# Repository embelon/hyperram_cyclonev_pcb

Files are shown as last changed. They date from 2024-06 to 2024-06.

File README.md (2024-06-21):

# Expansion PCB for Cyclone V SoC Development Kit

Using HSMC connector.

On board:
- 8MB HyperRAM memory: S27KL0641DABHI020
- 16MB HyperFlash : S26KL128SDABHI020
- 4MB QSPI FlashNOR: W25Q32JVSSIQ

I/O
- HDMI output
- 2 x PMOD (3V3): PMOD1 (J6), PMOD2 (7)
- 1 x PMOD (3V3 or 5V): PMOD3 (J5)
- 8bit LA header (shared signals with PMOD3/J5)
- 7 debug signals

### Images
top
bottom

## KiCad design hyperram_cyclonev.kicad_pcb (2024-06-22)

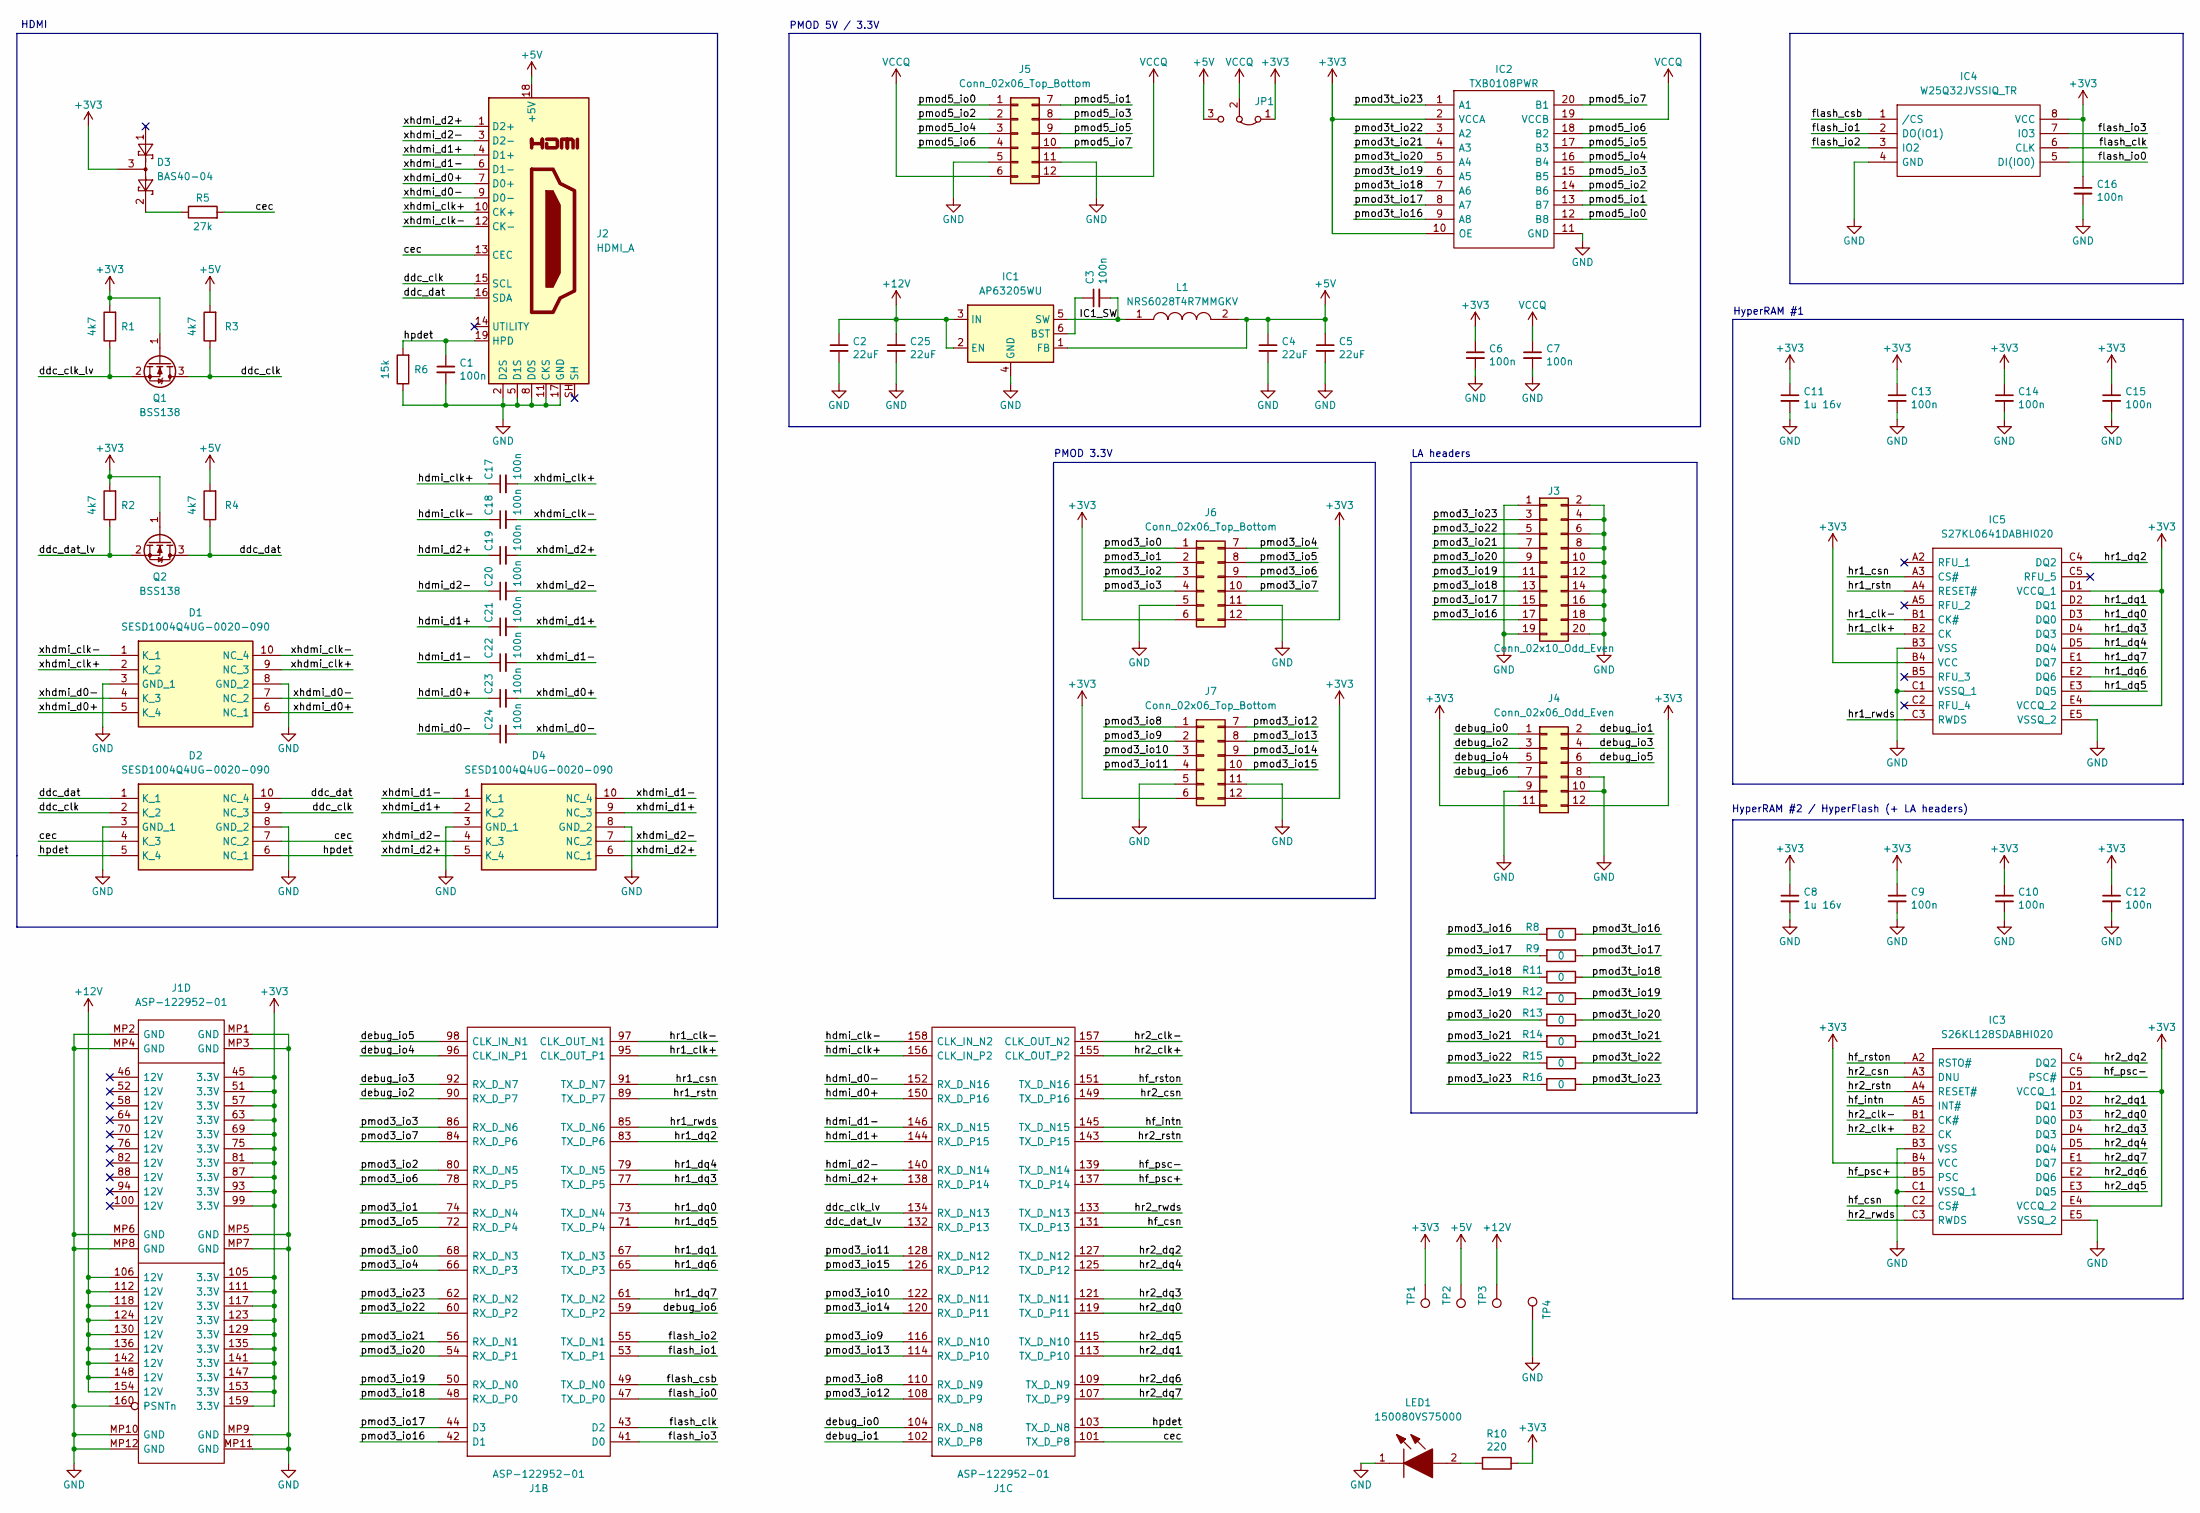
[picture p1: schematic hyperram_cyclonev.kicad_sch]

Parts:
C1, C9, C10, C12, C13, C14, C15, C16: 100n; C_0603_1608Metric_Pad1.08x0.95mm_HandSolder; Part CGA3E2X7R1H223K080AA
C2, C4, C5, C25: 22uF; C_0805_2012Metric_Pad1.18x1.45mm_HandSolder; Part CL21A226MAYNNNE
C3, C6, C7: 100n; C_0603_1608Metric_Pad1.08x0.95mm_HandSolder; Part 06033C104KAT2A
C8, C11: 1u 16v; C_0805_2012Metric_Pad1.18x1.45mm_HandSolder; Part CL10A105KO8NNNC
C17, C18, C19, C20, C21, C22, C23, C24: 100n; C_0402_1005Metric_Pad0.74x0.62mm_HandSolder; Part 06033C104KAT2A
D1, D2, D4: SESD1004Q4UG-0020-090; SESD1004Q4UG0020090; Mouser Part Number 650-SESD1004Q4UG0020
D3: BAS40-04; SOT-23
IC1: AP63205WU; TSOT-23-6
IC2: TXB0108PWR; SOP65P640X120-20N; Mouser Part Number 595-TXB0108PWR
IC3: S26KL128SDABHI020; BGA24C100P5X5_600X800X100; Mouser Part Number 727-S26KL128SDABHI02
IC4: W25Q32JVSSIQ_TR; SOIC127P790X216-8N; Mouser Part Number 454-W25Q32JVSSIQTR
IC5: S27KL0641DABHI020; BGA24C100P5X5_600X800X100; Manufacturer_Part_Number S27KL0641DABHI020; Mouser Part Number 727-S27KL0641DABHI02
J1: ASP-122952-01; ASP12295201; Manufacturer_Part_Number ASP-122952-01; Mouser Part Number 200-ASP-122952-01
J2: HDMI_A; 685119134923
J3: Conn_02x10_Odd_Even; PinHeader_2x10_P2.54mm_Vertical
J4: Conn_02x06_Odd_Even; PinHeader_2x06_P2.54mm_Vertical
J5, J6, J7: Conn_02x06_Top_Bottom; 610112249221_PMOD_Bottom
JP1: Jumper_3_Bridged12; PinHeader_1x03_P2.54mm_Vertical
L1: NRS6028T4R7MMGKV; NRS6028T4R7MMGK; Mouser Part Number 963-NRS6028T4R7MMGKV
LED1: 150080VS75000; LEDC2012X80N; Mouser Part Number 710-150080VS75000
Q1, Q2: BSS138; SOT-23
R1, R2, R3, R4: 4k7; R_0603_1608Metric_Pad0.98x0.95mm_HandSolder
R5: 27k; R_0603_1608Metric_Pad0.98x0.95mm_HandSolder
R6: 15k; R_0603_1608Metric_Pad0.98x0.95mm_HandSolder
R8, R9, R11, R12, R13, R14, R15, R16: 0; R_0402_1005Metric_Pad0.72x0.64mm_HandSolder
R10: 220; R_0603_1608Metric_Pad0.98x0.95mm_HandSolder; Part ‎RC0603JR-07100RL‎
TP1: 3V3; TestPoint_Pad_D1.0mm
TP2: 5V; TestPoint_Pad_D1.0mm
TP3: 12V; TestPoint_Pad_D1.0mm
TP4: GND; TestPoint_Pad_D1.0mm

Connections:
+3V3: C6.1, C8.1, C9.1, C10.1, C11.1, C12.1, C13.1, C14.1, C15.1, C16.1, D3.3, IC2.2 (VCCA), IC2.10 (OE), IC3.B4 (VCC), IC3.D1 (VCCQ_1), IC3.E4 (VCCQ_2), IC4.8 (VCC), IC5.B4 (VCC), IC5.D1 (VCCQ_1), IC5.E4 (VCCQ_2), J1.45 (3.3V), J1.51 (3.3V), J1.57 (3.3V), J1.63 (3.3V), J1.69 (3.3V), J1.75 (3.3V), J1.81 (3.3V), J1.87 (3.3V), J1.93 (3.3V), J1.99 (3.3V), J1.105 (3.3V), J1.111 (3.3V), J1.117 (3.3V), J1.123 (3.3V), J1.129 (3.3V), J1.135 (3.3V), J1.141 (3.3V), J1.147 (3.3V), J1.153 (3.3V), J1.159 (3.3V), J4.11, J4.12, J6.6, J6.12, J7.6, J7.12, JP1.1 (A), Q1.1 (G), Q2.1 (G), R1.2, R2.2, R10.1, TP1.1
+5V: C4.1, C5.1, IC1.1 (FB), J2.18 (+5V), JP1.3 (B), L1.2, R3.2, R4.2, TP2.1
+12V: C2.1, C25.1, IC1.2 (EN), IC1.3 (IN), J1.106 (12V), J1.112 (12V), J1.118 (12V), J1.124 (12V), J1.130 (12V), J1.136 (12V), J1.142 (12V), J1.148 (12V), J1.154 (12V), TP3.1
/IC1_SW: C3.2, IC1.5 (SW), L1.1
/cec: D2.4 (K_3), D2.7 (NC_2), J1.101 (TX_D_P8), J2.13 (CEC), R5.2
/ddc_clk: D2.2 (K_2), D2.9 (NC_3), J2.15 (SCL), Q1.3 (D), R3.1
/ddc_clk_lv: J1.134 (RX_D_N13), Q1.2 (S), R1.1
/ddc_dat: D2.1 (K_1), D2.10 (NC_4), J2.16 (SDA), Q2.3 (D), R4.1
/ddc_dat_lv: J1.132 (RX_D_P13), Q2.2 (S), R2.1
/debug_io0: J1.104 (RX_D_N8), J4.1
/debug_io1: J1.102 (RX_D_P8), J4.2
/debug_io2: J1.90 (RX_D_P7), J4.3
/debug_io3: J1.92 (RX_D_N7), J4.4
/debug_io4: J1.96 (CLK_IN_P1), J4.5
/debug_io5: J1.98 (CLK_IN_N1), J4.6
/debug_io6: J1.59 (TX_D_P2), J4.7
/flash_clk: IC4.6 (CLK), J1.43 (D2)
/flash_csb: IC4.1 (/CS), J1.49 (TX_D_N0)
/flash_io0: IC4.5 (DI(IO0)), J1.47 (TX_D_P0)
/flash_io1: IC4.2 (DO(IO1)), J1.53 (TX_D_P1)
/flash_io2: IC4.3 (IO2), J1.55 (TX_D_N1)
/flash_io3: IC4.7 (IO3), J1.41 (D0)
/hdmi_clk+: C17.1, J1.156 (CLK_IN_P2)
/hdmi_clk-: C18.1, J1.158 (CLK_IN_N2)
/hdmi_d0+: C23.1, J1.150 (RX_D_P16)
/hdmi_d0-: C24.1, J1.152 (RX_D_N16)
/hdmi_d1+: C21.1, J1.144 (RX_D_P15)
/hdmi_d1-: C22.1, J1.146 (RX_D_N15)
/hdmi_d2+: C19.1, J1.138 (RX_D_P14)
/hdmi_d2-: C20.1, J1.140 (RX_D_N14)
/hf_csn: IC3.C2 (CS#), J1.131 (TX_D_P13)
/hf_intn: IC3.A5 (INT#), J1.145 (TX_D_N15)
/hf_psc+: IC3.B5 (PSC), J1.137 (TX_D_P14)
/hf_psc-: IC3.C5 (PSC#), J1.139 (TX_D_N14)
/hf_rston: IC3.A2 (RSTO#), J1.151 (TX_D_N16)
/hpdet: C1.1, D2.5 (K_4), D2.6 (NC_1), J1.103 (TX_D_N8), J2.19 (HPD), R6.2
/hr1_clk+: IC5.B2 (CK), J1.95 (CLK_OUT_P1)
/hr1_clk-: IC5.B1 (CK#), J1.97 (CLK_OUT_N1)
/hr1_csn: IC5.A3 (CS#), J1.91 (TX_D_N7)
/hr1_dq0: IC5.D3 (DQ0), J1.73 (TX_D_N4)
/hr1_dq1: IC5.D2 (DQ1), J1.67 (TX_D_N3)
/hr1_dq2: IC5.C4 (DQ2), J1.83 (TX_D_P6)
/hr1_dq3: IC5.D4 (DQ3), J1.77 (TX_D_P5)
/hr1_dq4: IC5.D5 (DQ4), J1.79 (TX_D_N5)
/hr1_dq5: IC5.E3 (DQ5), J1.71 (TX_D_P4)
/hr1_dq6: IC5.E2 (DQ6), J1.65 (TX_D_P3)
/hr1_dq7: IC5.E1 (DQ7), J1.61 (TX_D_N2)
/hr1_rstn: IC5.A4 (RESET#), J1.89 (TX_D_P7)
/hr1_rwds: IC5.C3 (RWDS), J1.85 (TX_D_N6)
/hr2_clk+: IC3.B2 (CK), J1.155 (CLK_OUT_P2)
/hr2_clk-: IC3.B1 (CK#), J1.157 (CLK_OUT_N2)
/hr2_csn: IC3.A3 (DNU), J1.149 (TX_D_P16)
/hr2_dq0: IC3.D3 (DQ0), J1.119 (TX_D_P11)
/hr2_dq1: IC3.D2 (DQ1), J1.113 (TX_D_P10)
/hr2_dq2: IC3.C4 (DQ2), J1.127 (TX_D_N12)
/hr2_dq3: IC3.D4 (DQ3), J1.121 (TX_D_N11)
/hr2_dq4: IC3.D5 (DQ4), J1.125 (TX_D_P12)
/hr2_dq5: IC3.E3 (DQ5), J1.115 (TX_D_N10)
/hr2_dq6: IC3.E2 (DQ6), J1.109 (TX_D_N9)
/hr2_dq7: IC3.E1 (DQ7), J1.107 (TX_D_P9)
/hr2_rstn: IC3.A4 (RESET#), J1.143 (TX_D_P15)
/hr2_rwds: IC3.C3 (RWDS), J1.133 (TX_D_N13)
/pmod3_io0: J1.68 (RX_D_N3), J6.1
/pmod3_io1: J1.74 (RX_D_N4), J6.2
/pmod3_io2: J1.80 (RX_D_N5), J6.3
/pmod3_io3: J1.86 (RX_D_N6), J6.4
/pmod3_io4: J1.66 (RX_D_P3), J6.7
/pmod3_io5: J1.72 (RX_D_P4), J6.8
/pmod3_io6: J1.78 (RX_D_P5), J6.9
/pmod3_io7: J1.84 (RX_D_P6), J6.10
/pmod3_io8: J1.110 (RX_D_N9), J7.1
/pmod3_io9: J1.116 (RX_D_N10), J7.2
/pmod3_io10: J1.122 (RX_D_N11), J7.3
/pmod3_io11: J1.128 (RX_D_N12), J7.4
/pmod3_io12: J1.108 (RX_D_P9), J7.7
/pmod3_io13: J1.114 (RX_D_P10), J7.8
/pmod3_io14: J1.120 (RX_D_P11), J7.9
/pmod3_io15: J1.126 (RX_D_P12), J7.10
/pmod3_io16: J1.42 (D1), J3.17, R8.2
/pmod3_io17: J1.44 (D3), J3.15, R9.2
/pmod3_io18: J1.48 (RX_D_P0), J3.13, R11.2
/pmod3_io19: J1.50 (RX_D_N0), J3.11, R12.2
/pmod3_io20: J1.54 (RX_D_P1), J3.9, R13.2
/pmod3_io21: J1.56 (RX_D_N1), J3.7, R14.2
/pmod3_io22: J1.60 (RX_D_P2), J3.5, R15.2
/pmod3_io23: J1.62 (RX_D_N2), J3.3, R16.2
/pmod3t_io16: IC2.9 (A8), R8.1
/pmod3t_io17: IC2.8 (A7), R9.1
/pmod3t_io18: IC2.7 (A6), R11.1
/pmod3t_io19: IC2.6 (A5), R12.1
/pmod3t_io20: IC2.5 (A4), R13.1
/pmod3t_io21: IC2.4 (A3), R14.1
/pmod3t_io22: IC2.3 (A2), R15.1
/pmod3t_io23: IC2.1 (A1), R16.1
/pmod5_io0: IC2.12 (B8), J5.1
/pmod5_io1: IC2.13 (B7), J5.7
/pmod5_io2: IC2.14 (B6), J5.2
/pmod5_io3: IC2.15 (B5), J5.8
/pmod5_io4: IC2.16 (B4), J5.3
/pmod5_io5: IC2.17 (B3), J5.9
/pmod5_io6: IC2.18 (B2), J5.4
/pmod5_io7: IC2.20 (B1), J5.10
/xhdmi_clk+: C17.2, D1.2 (K_2), D1.9 (NC_3), J2.10 (CK+)
/xhdmi_clk-: C18.2, D1.1 (K_1), D1.10 (NC_4), J2.12 (CK-)
/xhdmi_d0+: C23.2, D1.5 (K_4), D1.6 (NC_1), J2.7 (D0+)
/xhdmi_d0-: C24.2, D1.4 (K_3), D1.7 (NC_2), J2.9 (D0-)
/xhdmi_d1+: C21.2, D4.2 (K_2), D4.9 (NC_3), J2.4 (D1+)
/xhdmi_d1-: C22.2, D4.1 (K_1), D4.10 (NC_4), J2.6 (D1-)
/xhdmi_d2+: C19.2, D4.5 (K_4), D4.6 (NC_1), J2.1 (D2+)
/xhdmi_d2-: C20.2, D4.4 (K_3), D4.7 (NC_2), J2.3 (D2-)
GND: C1.2, C2.2, C4.2, C5.2, C6.2, C7.2, C8.2, C9.2, C10.2, C11.2, C12.2, C13.2, C14.2, C15.2, C16.2, C25.2, D1.3 (GND_1), D1.8 (GND_2), D2.3 (GND_1), D2.8 (GND_2), D4.3 (GND_1), D4.8 (GND_2), IC1.4 (GND), IC2.11 (GND), IC3.B3 (VSS), IC3.C1 (VSSQ_1), IC3.E5 (VSSQ_2), IC4.4 (GND), IC5.B3 (VSS), IC5.C1 (VSSQ_1), IC5.E5 (VSSQ_2), J1.160 (PSNTn), J1.MP1 (GND), J1.MP2 (GND), J1.MP3 (GND), J1.MP4 (GND), J1.MP5 (GND), J1.MP6 (GND), J1.MP7 (GND), J1.MP8 (GND), J1.MP9 (GND), J1.MP10 (GND), J1.MP11 (GND), J1.MP12 (GND), J2.2 (D2S), J2.5 (D1S), J2.8 (D0S), J2.11 (CKS), J2.17 (GND), J3.1, J3.2, J3.4, J3.6, J3.8, J3.10, J3.12, J3.14, J3.16, J3.18, J3.19, J3.20, J4.8, J4.9, J4.10, J5.5, J5.11, J6.5, J6.11, J7.5, J7.11, LED1.1, R6.1, TP4.1
unnamed: D3.2, R5.1
unnamed: C3.1, IC1.6 (BST)
unnamed: LED1.2, R10.2
VCCQ: C7.1, IC2.19 (VCCB), J5.6, J5.12, JP1.2 (C)

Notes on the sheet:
PMOD 3.3V
LA headers
HDMI
HyperRAM #2 / HyperFlash (+ LA headers)
HyperRAM #1
PMOD 5V / 3.3V

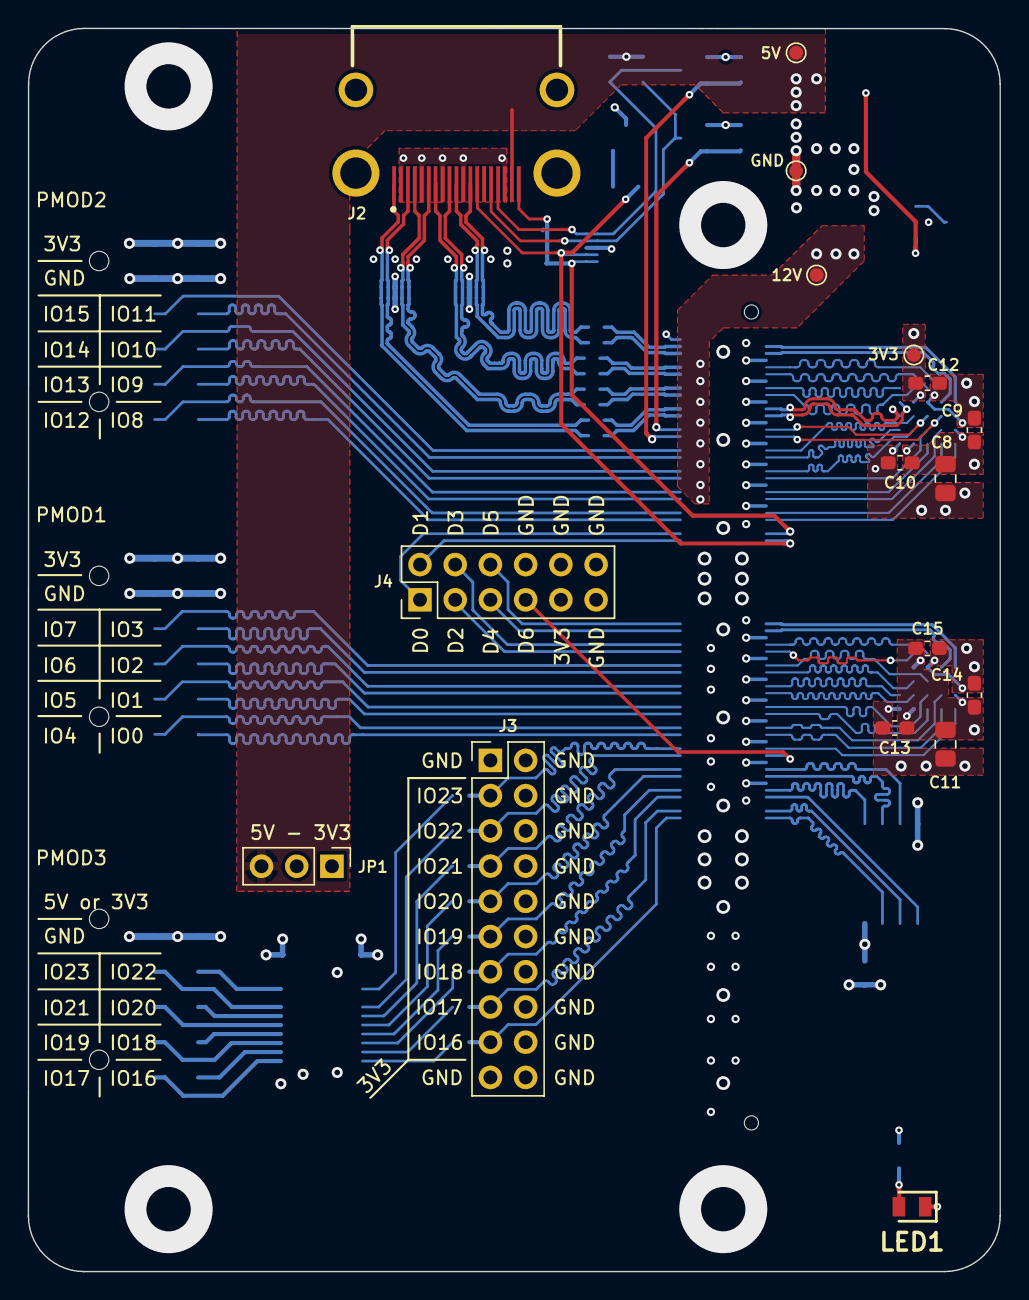
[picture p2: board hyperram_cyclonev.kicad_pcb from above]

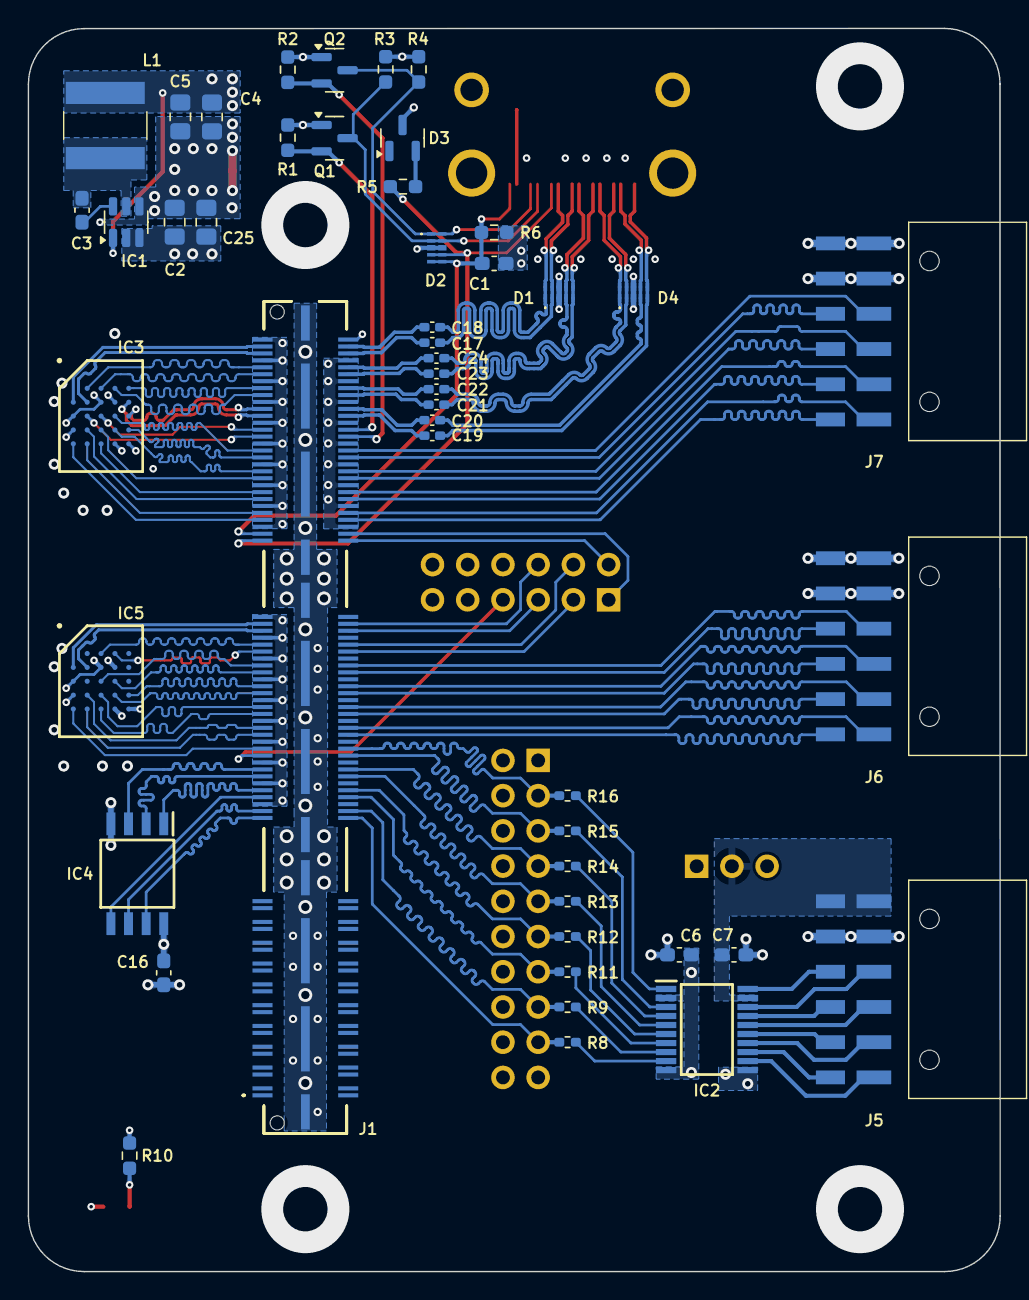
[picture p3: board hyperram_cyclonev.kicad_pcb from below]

Board: 4 copper layers, 70.1 x 89.6 mm, 65 parts (48 on the bottom side), 115 nets.

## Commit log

2022-09-15 Added PCB library
2022-10-16 Added DC/DC converter to get 5V for PMOD and HDMI from 12V. Changed two TXB0104 to one TXB0108 for PMOD 5V.
    [hyperram_cyclonev.kicad_sch]
2022-10-24 Updated schematics, made connections between PMODs, HyperBUS devices, Debug Header, QSPI NOR Flash, HDMI and HSMC.
    [hyperram_cyclonev.kicad_sch]
2023-08-11 Migrated to KiCad 7.
2023-08-11 Added 100nF capacitors in series for HDMI signals to get TMDS working with LVDS3 outputs on FPGA.
    [hyperram_cyclonev.kicad_sch]
2023-08-15 Fixed 2 issues with unconnected signals.
    [hyperram_cyclonev.kicad_sch]
2023-08-15 Updated symbols and footprints libraries.
2024-05-12 Fixed Schematics DRC warnings
    [hyperram_cyclonev.kicad_sch]
2024-05-13 Decreased number of ERC complaints. Assigned missing packages.
    [hyperram_cyclonev.kicad_sch]
2024-05-13 Loaded components into PCB.
    [hyperram_cyclonev.kicad_pcb, hyperram_cyclonev.kicad_sch]
2024-05-14 Fixed PCB footprint for PMOD
2024-05-14 Updated PCB footprint for HSMC
2024-05-14 Simplified schematic, removing unnecessary elements
    [hyperram_cyclonev.kicad_sch]
2024-05-14 Created edge.cuts. Updated PCB from schematic.
    [hyperram_cyclonev.kicad_pcb]
2024-05-15 Fixed issue with PMOD pins assignment
    [hyperram_cyclonev.kicad_pcb, hyperram_cyclonev.kicad_sch]
2024-05-16 Adjusted PCB dimensions. Moved components to the back side
    [hyperram_cyclonev.kicad_pcb]
2024-05-17 Changed two connectors from SMD to THT
    [hyperram_cyclonev.kicad_pcb, hyperram_cyclonev.kicad_sch]
2024-05-17 Rearrange signals assignments to simplify routing.
    [hyperram_cyclonev.kicad_pcb, hyperram_cyclonev.kicad_sch]
2024-05-17 Changed footprint in library from SMD to THT
2024-05-17 Reaarranged signals assignments to simplify routing
    [hyperram_cyclonev.kicad_pcb, hyperram_cyclonev.kicad_sch]
2024-05-22 Set constraints for PCBWay: 6/6mil, hole 0.25mm. First try for routing HyperRAM with trace length matching.
    [hyperram_cyclonev.kicad_pcb]
2024-05-23 Optimizing signal assigments and component placement to simplify routing.
    [hyperram_cyclonev.kicad_pcb, hyperram_cyclonev.kicad_sch]
2024-05-27 Fixed differential pairs designators for HyperRAM clk and psc and HDMI clk and data.
    [hyperram_cyclonev.kicad_pcb, hyperram_cyclonev.kicad_sch]
2024-06-11 Changed order of HDMI data signals to avoid crossing
    [hyperram_cyclonev.kicad_sch]
2024-06-11 Decreased board area. Fixed HyperRAM clk diff pair routing. First try for HDMI diff pair routing.
    [hyperram_cyclonev.kicad_pcb]
2024-06-12 Added additional resistors on LA / PMOD path
    [hyperram_cyclonev.kicad_sch]
2024-06-12 Routed almost all single ended signals, except HDMI and power
    [hyperram_cyclonev.kicad_pcb]
2024-06-13 Routed HDMI differential signals for a first time, still with unmatched lenghts between pairs
    [hyperram_cyclonev.kicad_pcb]
2024-06-14 Added width/space definition for differential traces
2024-06-14 Fixed pin numbering for SESD Series TVS Diode Array
2024-06-14 Fixed signals connection to SESD Series TVS Diode Array
    [hyperram_cyclonev.kicad_sch]
2024-06-14 Decreased courtyyard/keepout area for SESD Series TVS Diode Array in DFN 0802 package
2024-06-14 Updated PCB with latest fixes in schematic related to SESD Series TVS Diode Array
    [hyperram_cyclonev.kicad_pcb]
2024-06-18 Added symbol for new component SESD1004, TVS Diode Array, to the library
2024-06-18 Added footprint for new component SESD1004, TVS Diode Array, to the library
2024-06-18 Changed min clearance to 5mils, 0.127mm. Added new track 0,254mm.
2024-06-18 Changed SESD Series TVS Diode Array to different model. Rearranged schematic.
    [hyperram_cyclonev.kicad_sch]
2024-06-18 Updated footprints for changed SESD Series TVS Diode Arrays
    [hyperram_cyclonev.kicad_sch]
2024-06-18 Decreased courtyyard/keepout area for SESD Series TVS Diode Array in DFN 1004 package
2024-06-18 Updated SESD Series TVS Diode Arrays on PCB
    [hyperram_cyclonev.kicad_pcb]
2024-06-19 Routed HDMI differential pairs with intra-pair lenght matching
    [hyperram_cyclonev.kicad_pcb]
2024-06-19 Equalized lenghts of HDMI differential pairs.
    [hyperram_cyclonev.kicad_pcb]
2024-06-19 Connected directly +5P with +5V power
    [hyperram_cyclonev.kicad_sch]
2024-06-19 Changed clearance back to 0,1524mm / 6mils to route all except HDMI diff pairs
2024-06-19 Routed remaining HDMI signals. Routed DC/DC SWPS for +12V to +5V conversion
    [hyperram_cyclonev.kicad_pcb]
2024-06-21 Added filled areas for GND and 3V3 supplying HyperRAM memory
    [hyperram_cyclonev.kicad_pcb]
2024-06-21 Placed all local filled areas for 3V3, 5V, GND
    [hyperram_cyclonev.kicad_pcb]
2024-06-21 Added second filtering input capacitor for DC/DC converter
    [hyperram_cyclonev.kicad_pcb, hyperram_cyclonev.kicad_sch]
2024-06-21 Added GND and 3V3 fill areas
    [hyperram_cyclonev.kicad_pcb]
2024-06-21 Marked unused 12V pins as NC
    [hyperram_cyclonev.kicad_pcb, hyperram_cyclonev.kicad_sch]
2024-06-21 Fixed meaningful ERC errors in schematic
    [hyperram_cyclonev.kicad_sch]
2024-06-21 Modified HDMI footprint to match schematic symbol (shielding connections)
2024-06-21 Fixed DRC errors
    [hyperram_cyclonev.kicad_pcb]
2024-06-21 Decreased number of shielding, return path Vias for GND around HDMI diff pairs
    [hyperram_cyclonev.kicad_pcb]
2024-06-21 Fixed DRC warnings related to f.silkscreen
    [hyperram_cyclonev.kicad_pcb, hyperram_cyclonev.kicad_sch]
2024-06-21 Fixed DRC warnings related to b.silkscreen
    [hyperram_cyclonev.kicad_pcb]
2024-06-21 Added signal names on f.silkscreen
    [hyperram_cyclonev.kicad_pcb]
2024-06-21 Added render action for PCB
2024-06-22 Added teardrops to all tracks connected to vias. Refilled all areas again.
    [hyperram_cyclonev.kicad_pcb]
